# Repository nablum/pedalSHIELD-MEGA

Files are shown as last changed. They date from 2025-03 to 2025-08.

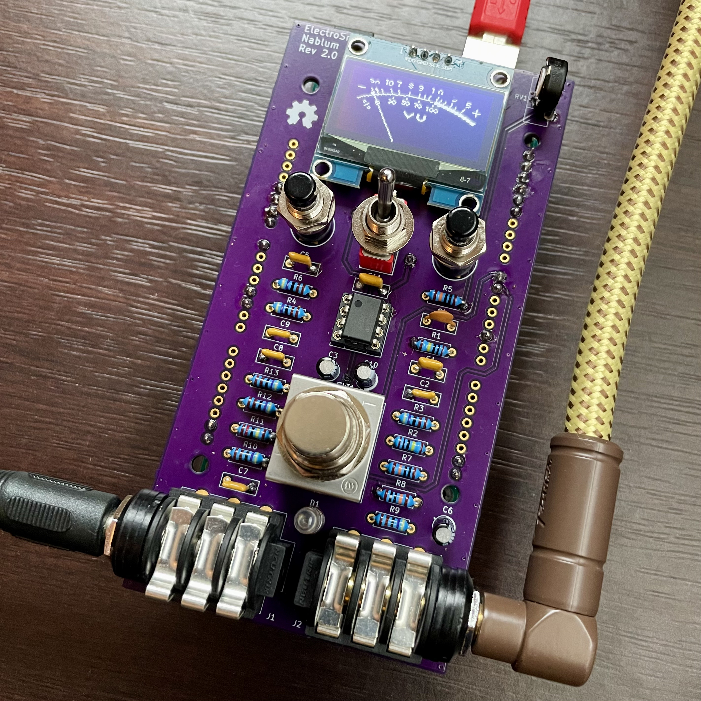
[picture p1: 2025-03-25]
hardware/kicad/pedalSHIELD_MEGA.jpg

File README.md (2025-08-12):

<p align="center">
    
</p>







A programmable guitar effects shield for Arduino MEGA, featuring OLED display, true-bypass footswitch, and DSP-ready input/output stages. Based on pedalSHIELD MEGA by [ElectroSmash](https://www.electrosmash.com/pedalshield-mega)  

<p align="center">
    device
</p>

## 📦 What’s Included

- ✅ **KiCad project**: schematic & PCB layout files for the hardware shield
- ✅ **Arduino examples**: boost, fuzz, delay, and other DSP sketches
- ✅ **Bill of Materials**: CSV file with component list and Mouser links
- ✅ **Documentation**: assembly guide, schematic diagrams, signal flow

## 🛠️ Assembly & Programming

1. **Clone the repository**:

    ```bash
    git clone https://github.com/nablum/pedalSHIELD-MEGA.git
    cd pedalSHIELD-MEGA
    ```

2. **Build the PCB** with KiCad or order the board from a fab using the provided Gerbers.

3. **Solder the components** according to the [Assembly Guide](https://www.electrosmash.com/media/kunena/attachments/631/How-to-Build-pedalSHIELD-MEGA-V1.1.pdf).

4. **Upload an effect sketch** to your Arduino MEGA using Arduino IDE.
5. **Plug and play**:
    - Guitar IN → Input Jack
    - Output → Amp or Audio Interface
    - Power → USB or DC JACK.

## 🎛️ Example Effects

Each audio effect is implemented in a separate folder under [`firmware/effects/`](./firmware/effects/):

| Effect Name | Description |
|---|---|
| BitCrusher | Reduces resolution and sample rate for lo-fi textures |
| Chorus | Modulates pitch with delay to create a thickening effect  |
| ChorusOrVibrato | Blendable chorus and vibrato with adjustable depth |
| Clean | Transparent clean boost (reference circuit) |
| Distortion | Hard-clipping distortion effect |
| Echo | Simple digital delay with feedback loop |
| Fuzz | Saturated high-gain fuzz effect |
| MultiEffects | Combination of multiple effects in a single patch |
| OctaveCrusher | Bit reduction with added octave-up/down harmonics |
| Octaver | Mixes original with octave-down processed signal |
| Reverb | Simulates ambient reverb using delay-based algorithm |
| Tremolo | Volume modulation using a low-frequency oscillator |
| Vibrato | Pitch modulation effect for expressive shimmer |

## ⚙️ Hardware Specs

- Compatible with **Arduino MEGA 2560**
- 128×64 I²C OLED display (SSD1306)
- True-bypass footswitch with relay
- Stereo audio jacks with analog preamp/output
- Powered via **12 V DC (center-negative)**

## ❓ Troubleshooting

- **OLED not lighting up** → Double-check I²C wiring and 4.7k pull-up resistors.
- **No audio output** → Ensure signal chain is complete and shield is powered.
- **Arduino upload fails** → Check USB port, board selection, and serial permissions.

## 📚 Resources

- 🔬 [pedalSHIELD-MEGA Documentation – ElectroSmash](https://www.electrosmash.com/pedalshield-mega)  
  Official guide, schematics, theory of operation, and signal path details.

- 🧰 [Assembly Guide – PDF](https://www.electrosmash.com/media/kunena/attachments/631/How-to-Build-pedalSHIELD-MEGA-V1.1.pdf)  
  Step-by-step instructions with images for building the pedalSHIELD‑MEGA hardware.

- 📦 [u8glib – OLED Display Library](https://github.com/olikraus/u8glib)  
  Arduino graphics library used to drive the OLED screen (SSD1306, I²C).

- 💻 [Arduino IDE Downloads](https://www.arduino.cc/en/software/)  
  Install the Arduino IDE to compile and upload code to the MEGA 2560.

## 🤝 Contributing

Contributions are welcome! You can:

- Submit new audio effects or improvements to existing sketches.
- Suggest hardware upgrades (e.g. better op-amps, analog filtering).
- Improve documentation or add new troubleshooting tips.

Please open a pull request against the `main` branch and follow the coding style of existing files.

## 📄 License

- **Hardware (PCB files, schematics, BOM)**:  
  Licensed under [Creative Commons Attribution-NonCommercial 3.0 (CC BY-NC 3.0)](https://creativecommons.org/licenses/by-nc/3.0/)

- **Software (Arduino code, examples)**:  
  Licensed under the [MIT License](LICENSE)

## 📬 Contact

Created by [@nablum](https://github.com/nablum).  
For questions or collaboration ideas, feel free to open an issue or reach out directly.

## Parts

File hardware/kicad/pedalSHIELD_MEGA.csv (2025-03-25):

Reference | Description | Mouser | Value | Qty
A1 | Shield for Arduino Mega 2560 R3 | 782-A000067 | ~ | 1
C1,C11 | Unpolarized capacitor | SR211C | 100n | 2
C2,C5,C7,C8,C9 | Unpolarized capacitor | SR211C | 6.8n | 5
C3,C6,C10 | Polarized capacitor | ECE-A1EKA4R7 | 4.7u | 3
C4 | Unpolarized capacitor | SR211C | 270p | 1
D1 | LED, 5mm | 696-SSL-LX3044USBC | ~ | 1
J1,J2 | Audio Jack, 3 Poles (Stereo / TRS), Switched Poles (Normalling) | NMJ6HCD2 | ~ | 2
LCD1 | I2C connector for LCD display |  | ~ | 1
R1,R2 | Resistor | MFR-25FRF52 | 1M | 2
R3,R4,R6,R9,R10,R12,R13,R14,R15 | Resistor | MFR-25FRF52 | 4.7k | 9
R5,R7,R8 | Resistor | MFR-25FRF52 | 100k | 3
R11 | Resistor | MFR-25FRF52 | 1M2 | 1
RV1 | Trim-potentiometer | PT10LH01-504A2020 | 500k | 1
SW1 | Pushbutton Switches 3PDT STOMP/FOOT SW LATCHING 1A9VDC 9PIN | 107-SF17020F-32-21RL | ~ | 1
SW2 | Switch, single pole double throw | 100SP1T1B1M1QEH | ~ | 1
SW3,SW4 | Push button switch, two pins | 104-0013-EVX | ~ | 2
U1 | TL97x Output Rail-To-Rail Very-Low-Noise Operational Amplifiers | 595-TL972IP | ~ | 1

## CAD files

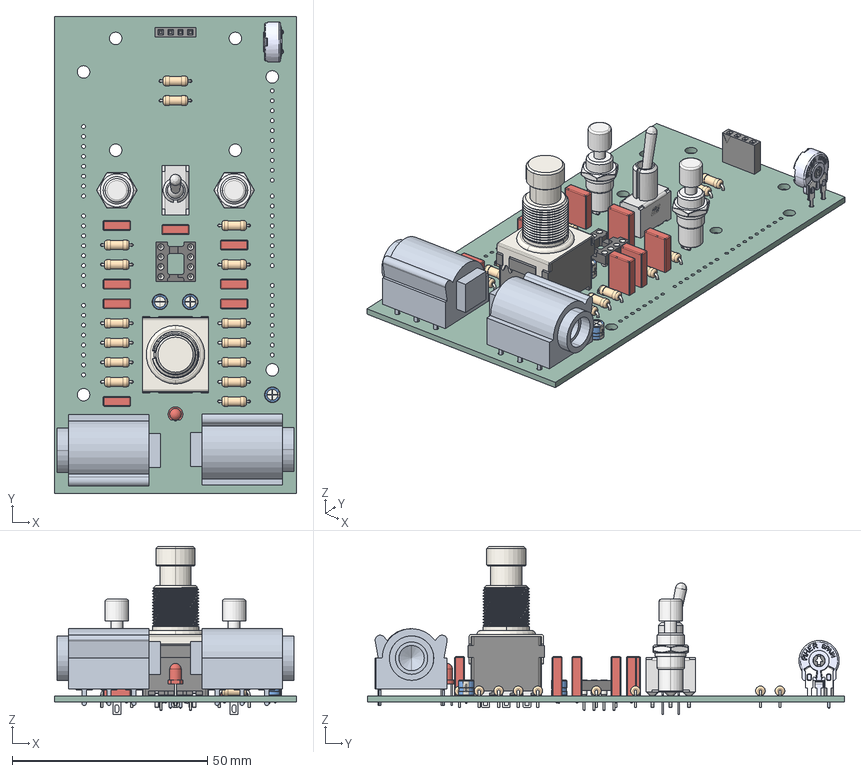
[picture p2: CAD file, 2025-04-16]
hardware/kicad/pedalSHIELD_MEGA.step
62.0 x 122.0 x 43.0 mm
C_Rect_L70mm_W25mm_P500mm x 8
ASSEMBLY
SF17020F-0302-21R-L-015
R_Axial_DIN0207_L63mm_D25mm_P762mm_Horizontal x 15
NMJ6HCD2 x 2
LED_D3.0mm
DIP_8_W762mm_Socket
CP_Radial_D40mm_P150mm x 3
P:\E-Switch Secure\3D_MODELS_STP_FORMAT\100SPxT1B1M1xE.stp
PT10_PTC10_10LH01
103-1013-EVX x 2
pedalSHIELD_MEGA_PCB

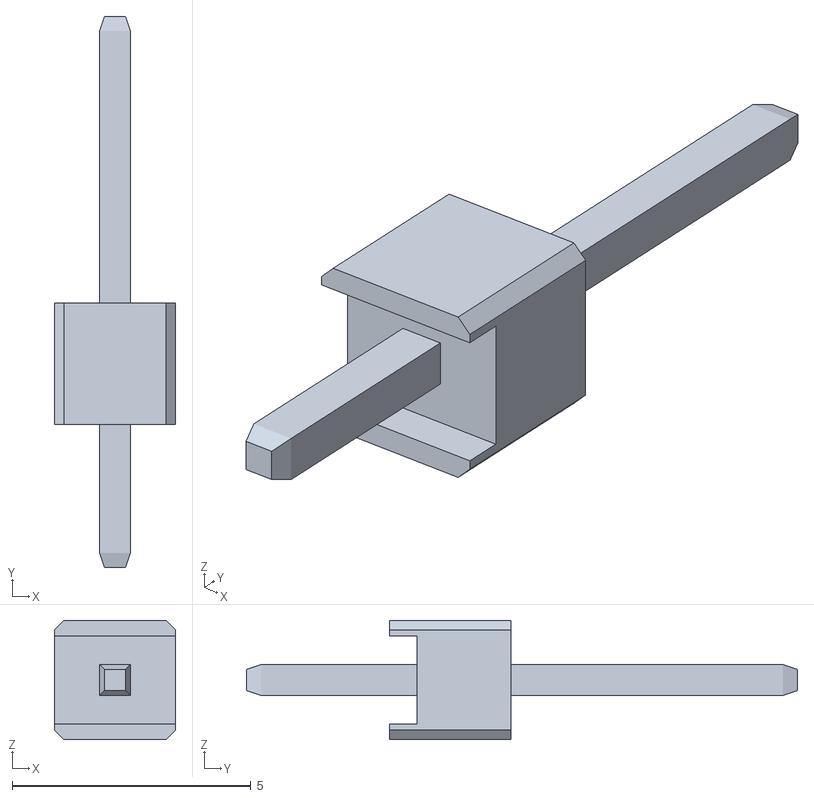
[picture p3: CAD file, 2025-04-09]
hardware/openscad/model3D/pinHeader.stl
2.54 x 11.5 x 2.50

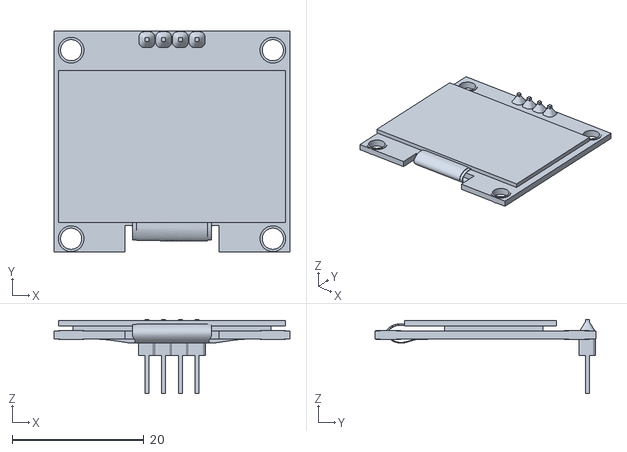
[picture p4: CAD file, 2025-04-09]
hardware/openscad/model3D/displayOLED.stl
35.8 x 33.5 x 11.3

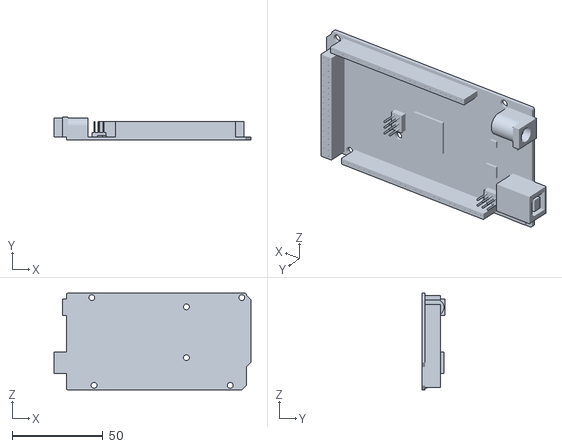
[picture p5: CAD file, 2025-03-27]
hardware/openscad/model3D/ArduinoMega_2560.stl
108.3 x 12.5 x 53.3

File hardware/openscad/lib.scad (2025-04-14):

// Licensed under a Creative Commons Attribution 4.0 International License.

// Library
include <NopSCADlib/lib.scad>

// Modules
module importPedal(){
    // Origin alignment
    translate([0.5,11.5,0]){
        // Arduino Mega
        rotate([90,0,-90]) import("./model3D/ArduinoMega_2560.stl");
        // PCB
        translate([-0.5,-11.5,12]) import("./model3D/pedalSHIELD_MEGA.stl");
        // LCD
        translate([-0.5,29.6,24.8]) import("./model3D/displayOLED.stl");
        // Pin headers
        generate_pin_header(8,[24.3,-37.1,12],"z","y","up"); // Bottom right side
        generate_pin_header(8,[24.3,-14.3,12],"z","y","up"); // Middle right side
        generate_pin_header(10,[24.3,7.6,12],"z","y","up"); // Top right side
        generate_pin_header(8,[-24,-42.2,12],"z","y","up"); // Bottom left side
        generate_pin_header(8,[-24,-19.3,12],"z","y","up"); // Middle left side
        generate_pin_header(8,[-24,3.5,12],"z","y","up"); // Top left side
    }
}

module buildTopPanel(){
    difference(){
        // Top panel
        translate([0,0,$sideHeight-$topThickness/2]){
            cube([$caseWidth+2*$sideThickness*$topSideOverlap,$caseLength+2*$sideThickness*$topSideOverlap,$topThickness],center=true);
        }
        // Footswitch hole
        translate(concat($footSwitchHolePosition,$sideHeight-$topThickness/2)){ 
            cylinder($topThickness+$fs,d1=$footSwitchHoleDiameter,d2=$footSwitchHoleDiameter,center=true);
        }
        // Push button left
        translate(concat($pushButtonHolePosition[0],$sideHeight-$topThickness/2)){ 
            cylinder($topThickness+$fs,d1=$pushButtonHoleDiameter,d2=$pushButtonHoleDiameter,center=true);
        } 
        // Push button right
        translate(concat($pushButtonHolePosition[1],$sideHeight-$topThickness/2)){ 
            cylinder($topThickness+$fs,d1=$pushButtonHoleDiameter,d2=$pushButtonHoleDiameter,center=true);
        }
        // Toggle switch
        translate(concat($toggleSwitchHolePosition,$sideHeight-$topThickness/2)){ 
            cylinder($topThickness+$fs,d1=$toggleSwitchHoleDiameter,d2=$toggleSwitchHoleDiameter,center=true);
        }
        // LCD window
        if ($lcdWindowEnable){
            translate(concat($lcdWindowPosition,$sideHeight-$topThickness/2)){
                cube([$lcdWindowWidth,$lcdWindowLength,$topThickness+$fs],center=true);
            }
        }
        // Mount holes
        addMounts();
    }
}

module buildBottomPanel(){
    difference(){
        translate([0,0,-$baseThickness/2]) cube([$caseWidth,$caseLength,$baseThickness],center=true); // Base
        translate([0.5,11.5,-$cavityHeight/2]) cube([$cavityWidth,$cavityLength,$cavityHeight+$fs],center=true); // Cavity
        for(i=[0:len($screwPosition)-1]){ // Mount holders
            translate([$screwPosition[i][0],$screwPosition[i][1],-((nut_thickness($nutType)+$cavityHeight)/2)]){
                cylinder(nut_thickness($nutType)+$cavityHeight+$fs,nut_radius($nutType)+$fs,nut_radius($nutType)+$fs,$fn=6,center=true);
            }
        }
    }
}

module buildLeftPanel(){
    difference(){
        // Panel
        translate([-($caseWidth+$sideThickness)/2,0,($sideHeight-$baseThickness)/2]){
            cube([$sideThickness,$caseLength+2*$sideThickness,$sideHeight+$baseThickness],center=true);
        }
        // Jack connector hole
        translate(concat(-($caseWidth+$sideThickness)/2,$audioJackHolePosition[0][0],$audioJackHolePosition[0][1])){ 
            rotate([0,90,0]){ 
                cylinder($sideThickness+$fs,d1=$audioJackHoleDiameter,d2=$audioJackHoleDiameter,center=true);
            }
        }
        // Top panel overlap
        translate([0,0,$sideHeight-$topThickness/2]){
            cube([$caseWidth+2*$sideThickness*$topSideOverlap,$caseLength+2*$sideThickness*$topSideOverlap,$topThickness+$fs],center=true);
        }
    }
}

module buildRightPanel(){
    difference(){
        // Panel
        translate([($caseWidth+$sideThickness)/2,0,($sideHeight-$baseThickness)/2]){
            cube([$sideThickness,$caseLength+2*$sideThickness,$sideHeight+$baseThickness],center=true);
        }
        // Jack connector hole
        translate(concat(($caseWidth+$sideThickness)/2,$audioJackHolePosition[1][0],$audioJackHolePosition[1][1])){ 
            rotate([0,90,0]){ 
                cylinder($sideThickness+$fs,d1=$audioJackHoleDiameter,d2=$audioJackHoleDiameter,center=true);
            }
        }
        // Potentiometer hole
        translate(concat(($caseWidth+$sideThickness)/2,$potHolePosition[0],$potHolePosition[1])){ 
            rotate([0,90,0]){ 
                cylinder($sideThickness+$fs,d1=$potHoleDiameter,d2=$potHoleDiameter,center=true);
            }
        }
        // Top panel overlap
        translate([0,0,$sideHeight-$topThickness/2]){
            cube([$caseWidth+2*$sideThickness*$topSideOverlap,$caseLength+2*$sideThickness*$topSideOverlap,$topThickness+$fs],center=true);
        }
    }
}

module buildBackPanel(){
    difference(){
        // Panel
        translate([0,-($caseLength+$sideThickness)/2,($sideHeight-$baseThickness)/2]){
            cube([$caseWidth+2*$sideThickness,$sideThickness,$sideHeight+$baseThickness],center=true);
        }
        // Top panel overlap
        translate([0,0,$sideHeight-$topThickness/2]){
            cube([$caseWidth+2*$sideThickness*$topSideOverlap,$caseLength+2*$sideThickness*$topSideOverlap,$topThickness+$fs],center=true);
        }
    }
}

module buildFrontPanel(){
    difference(){
        // Panel
        translate([0,($caseLength+$sideThickness)/2,($sideHeight-$baseThickness)/2]){
            cube([$caseWidth+2*$sideThickness,$sideThickness,$sideHeight+$baseThickness],center=true);
        }
        // USB Hole
        translate([$usbHolePosition[0],($caseLength+$sideThickness)/2,$usbHolePosition[1]]){
            cube([$usbHoleWidth,$sideThickness+$fs,$usbHoleHeight],center=true);
        }
        // Power supply connector
        translate([$dcJackHolePosition[0],($caseLength+$sideThickness)/2,$dcJackHolePosition[1]]){
            cube([$dcJackHoleWidth,$sideThickness+$fs,$dcJackHoleHeight],center=true);
        }
        // Top panel overlap
        translate([0,0,$sideHeight-$topThickness/2]){
            cube([$caseWidth+2*$sideThickness*$topSideOverlap,$caseLength+2*$sideThickness*$topSideOverlap,$topThickness+$fs],center=true);
        }
    }
}

module import_pin_header(rotation=[0,0,0],translation=[0,0,0]){
    rotate(rotation){ 
        translate(translation){
            import("./model3D/pinHeader.stl");
        }
    }
}
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

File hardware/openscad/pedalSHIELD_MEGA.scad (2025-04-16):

// Licensed under a Creative Commons Attribution 4.0 International License.

// *** LIBRARY *** //
include <lib.scad>

// *** VISUALISATION *** //
view = "assembly"; // choose between "assembly", "printing", "cutting"
printing = true; // True for 3D print

// *** DIMENSIONS *** //
// System
$fa = 1; // Minimum angle
$fs = 0.1; // Minimum size

// Pedal
pedalWidth = 62;
pedalLength = 122;
pedalHeight = 33;

// Arduino
arduinoWidth = 53;
arduinoLength = 99;
arduinoHeight = 15;
arduinoWeldsHeight = 2.5;

// Cavity (to avoid conflict with arduino's welds)
$cavityWidth = arduinoWidth-2;
$cavityLength = arduinoLength-2;
$cavityHeight = arduinoWeldsHeight+0.5;

// Mounts
$nutType = M3_nut;
$screwType = M3_dome_screw;
$screwPosition = [[24.68,45.65], // X/Y
                  [24.68,-29.25],
                  [-23.55,46.9],
                  [-23.55,-35.6]];

// Case
$caseWidth = pedalWidth+0.5;
$caseLength = pedalLength+0.5;
$baseThickness = $cavityHeight+nut_thickness($nutType)+2;
$sideHeight = 34;
$sideThickness = 2;
$topThickness = 2;
$topSideOverlap = 0.5;

// Audio jack
$audioJackHoleDiameter = 12;
$audioJackHolePosition = [[-49.8,23.2], // Y/Z - Left/Right
                          [-49.8,23.2]]; 

// DC jack
$dcJackHolePosition = [-18.3,7.1]; // X/Z
$dcJackHoleWidth = 9.5;
$dcJackHoleHeight = 12;

// USB
$usbHolePosition = [12.1,7]; // X/Z
$usbHoleWidth = 13;
$usbHoleHeight = 12.5;

// Potentiometer
$potHoleDiameter = 4;
$potHolePosition = [54.5,22.6]; // Y/Z

// Foot switch
$footSwitchHoleDiameter = 12.6;
$footSwitchHolePosition = [0,-25.5]; // X/Y

// Push buttons
$pushButtonHoleDiameter = 7;
$pushButtonHolePosition = [[-15,16.5], // X/Y - Left/Right
                           [15,16.5]];

// Toggle switch
$toggleSwitchHoleDiameter = 7;
$toggleSwitchHolePosition = [0,16.5]; // X/Y

// LCD window
$lcdWindowEnable = false;
$lcdWindowWidth = 31;
$lcdWindowLength = 16;
$lcdWindowPosition = [0,44];

// *** DESIGN *** //
if(view=="assembly") buildCase();
if(view=="printing") printCase();
if(view=="cutting") cutCase();

// *** MODULES *** //
module buildCase(){
    importPedal();
    addMounts();
    buildBottomPanel();
    buildLeftPanel();
    buildRightPanel();
    buildBackPanel(); 
    buildFrontPanel();
    color(alpha=0.5) buildTopPanel();
}

module printCase(){
    translate([0,0,$baseThickness]){
        buildBottomPanel();
        buildLeftPanel();
        buildRightPanel();
        buildBackPanel(); 
        buildFrontPanel();
    }
    translate([$caseWidth+5,0,-$sideHeight+$topThickness]){
        buildTopPanel();
    }
}

module cutCase(){
    projection(cut = false){
        buildTopPanel();
    }    
}

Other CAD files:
hardware/openscad/model3D/pedalSHIELD_MEGA.stl
hardware/openscad/pedalSHIELD_MEGA.stl

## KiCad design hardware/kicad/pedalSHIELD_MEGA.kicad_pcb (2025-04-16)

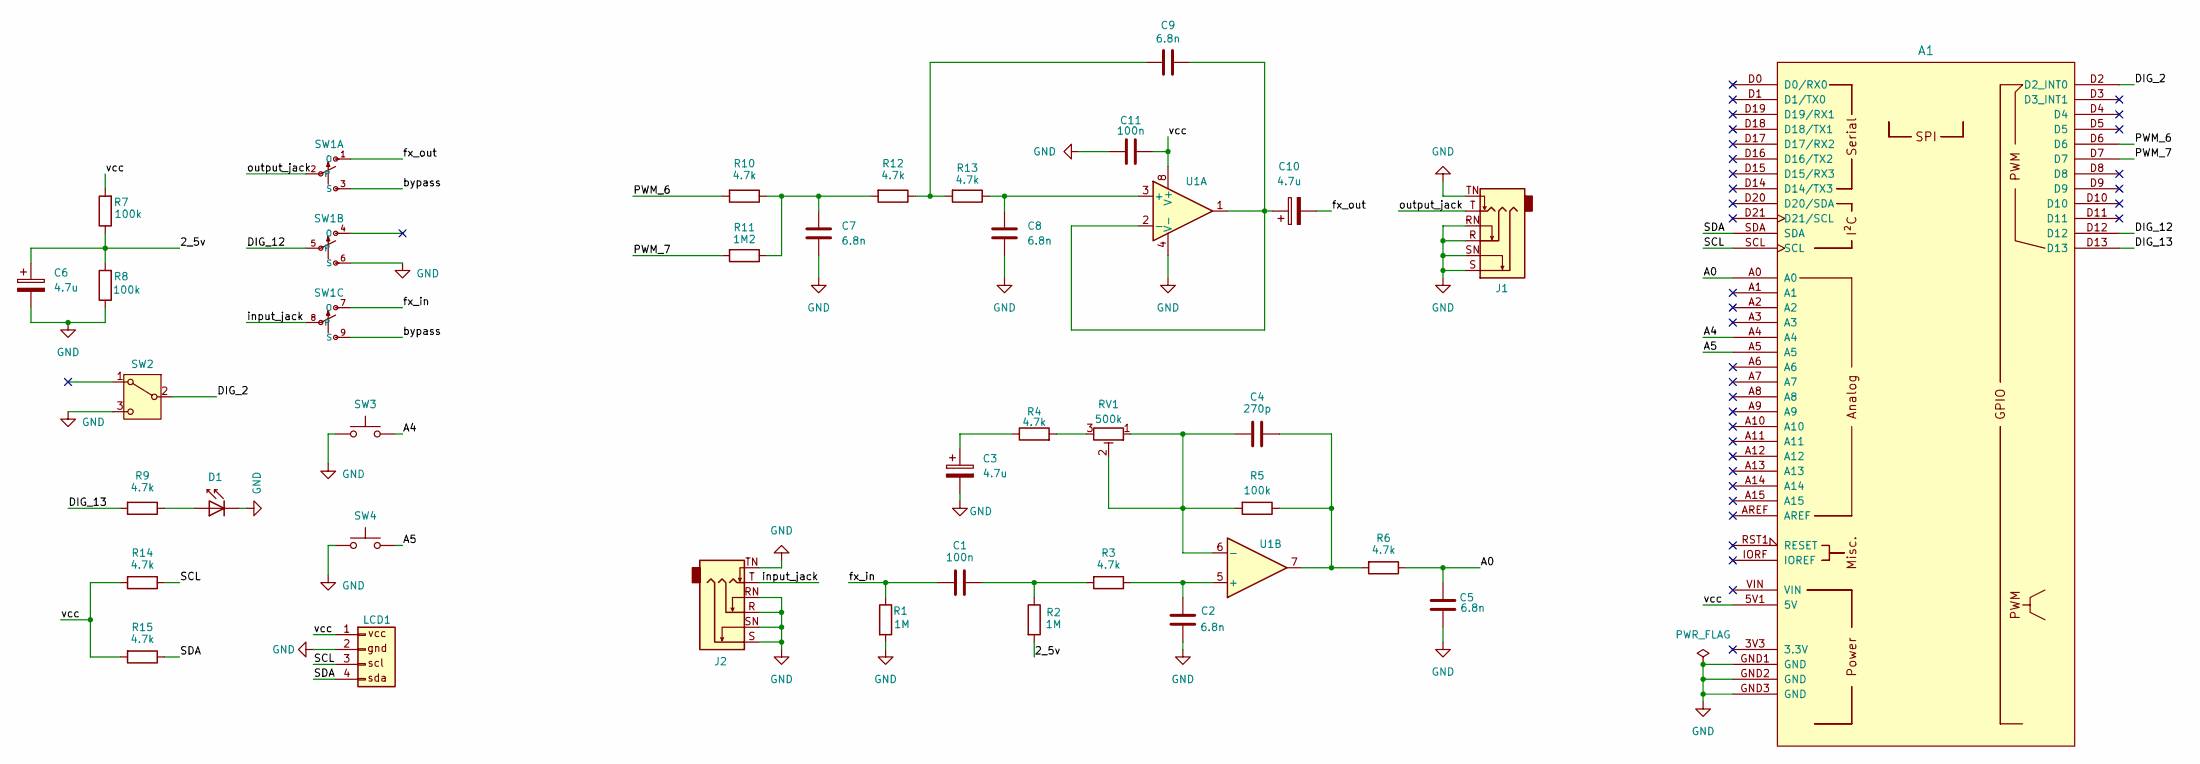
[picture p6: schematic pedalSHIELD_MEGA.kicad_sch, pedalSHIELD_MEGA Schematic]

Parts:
A1: Arduino_Mega2560_R3_Shield_pedalSHIELD_MEGA; Mouser 782-A000067
C1, C11: 100n; C_Rect_L7.0mm_W2.5mm_P5.00mm; Mouser SR211C
C2, C5, C7, C8, C9: 6.8n; C_Rect_L7.0mm_W2.5mm_P5.00mm; Mouser SR211C
C3, C6, C10: 4.7u; CP_Radial_D4.0mm_P1.50mm; Mouser ECE-A1EKA4R7
C4: 270p; C_Rect_L7.0mm_W2.5mm_P5.00mm; Mouser SR211C
D1: LED_D3.0mm; Mouser 696-SSL-LX3044USBC
J1, J2: Jack_6.35mm_Neutrik_NMJ6HCD2_Horizontal; Mouser NMJ6HCD2
LCD1: LCD_OLED_SH1106
R1, R2: 1M; R_Axial_DIN0207_L6.3mm_D2.5mm_P7.62mm_Horizontal; Mouser MFR-25FRF52
R3, R4, R6, R9, R10, R12, R13, R14, R15: 4.7k; R_Axial_DIN0207_L6.3mm_D2.5mm_P7.62mm_Horizontal; Mouser MFR-25FRF52
R5, R7, R8: 100k; R_Axial_DIN0207_L6.3mm_D2.5mm_P7.62mm_Horizontal; Mouser MFR-25FRF52
R11: 1M2; R_Axial_DIN0207_L6.3mm_D2.5mm_P7.62mm_Horizontal; Mouser MFR-25FRF52
RV1: 500k; Potentiometer_Piher_PT-10-H01_Horizontal; Mouser PT10LH01-504A2020
SW1: SF17020F030221RL015; Manufacturer_Part_Number SF17020F-0302-21R-L-015; Mouser 107-SF17020F-32-21RL
SW2: SW_SPDT_ 100SP1T1B1M1QEH; Mouser 100SP1T1B1M1QEH
SW3, SW4: SW_PUSH_104-0013-EVX; Mouser 104-0013-EVX
U1: DIP-8_W7.62mm_Socket_LongPads; Mouser 595-TL972IP

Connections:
/2_5v: C6.1, R2.2, R7.1, R8.2
/A0: A1.A0, C5.1, R6.1
/A4: A1.A4, SW3.2
/A5: A1.A5, SW4.2
/DIG_2: A1.D2 (D2_INT0), SW2.2 (B)
/DIG_12: A1.D12, SW1.5
/DIG_13: A1.D13, R9.2
/PWM_6: A1.D6, R10.2
/PWM_7: A1.D7, R11.2
/SCL: A1.SCL, LCD1.3, R14.1
/SDA: A1.SDA, LCD1.4, R15.1
/bypass: SW1.3 (S), SW1.9 (S)
/fx_in: C1.1, R1.1, SW1.7 (O)
/fx_out: C10.2, SW1.1 (O)
/input_jack: J2.T, SW1.8
/output_jack: J1.T, SW1.2
/vcc: A1.5V1 (5V), C11.2, LCD1.1, R7.2, R14.2, R15.2, U1.8 (V+)
GND: A1.GND1 (GND), A1.GND2 (GND), A1.GND3 (GND), C2.2, C3.2, C5.2, C6.2, C7.2, C8.2, C11.1, D1.1 (K), J1.R, J1.RN, J1.S, J1.SN, J1.TN, J2.R, J2.RN, J2.S, J2.SN, J2.TN, LCD1.2, R1.2, R8.1, SW1.6 (S), SW2.3 (C), SW3.1, SW4.1, U1.4 (V-)
unnamed: C1.2, R2.1, R3.2
unnamed: C3.1, R4.1
unnamed: C4.2, R5.1, R6.2, U1.7
unnamed: C7.1, R10.1, R11.1, R12.2
unnamed: C9.1, R12.1, R13.2
unnamed: D1.2 (A), R9.1
unnamed: R4.2, RV1.3
unnamed: C8.1, R13.1, U1.3 (+)
unnamed: C9.2, C10.1, U1.1, U1.2 (-)
unnamed: C2.1, R3.1, U1.5 (+)
unnamed: C4.1, R5.2, RV1.1, RV1.2, U1.6 (-)

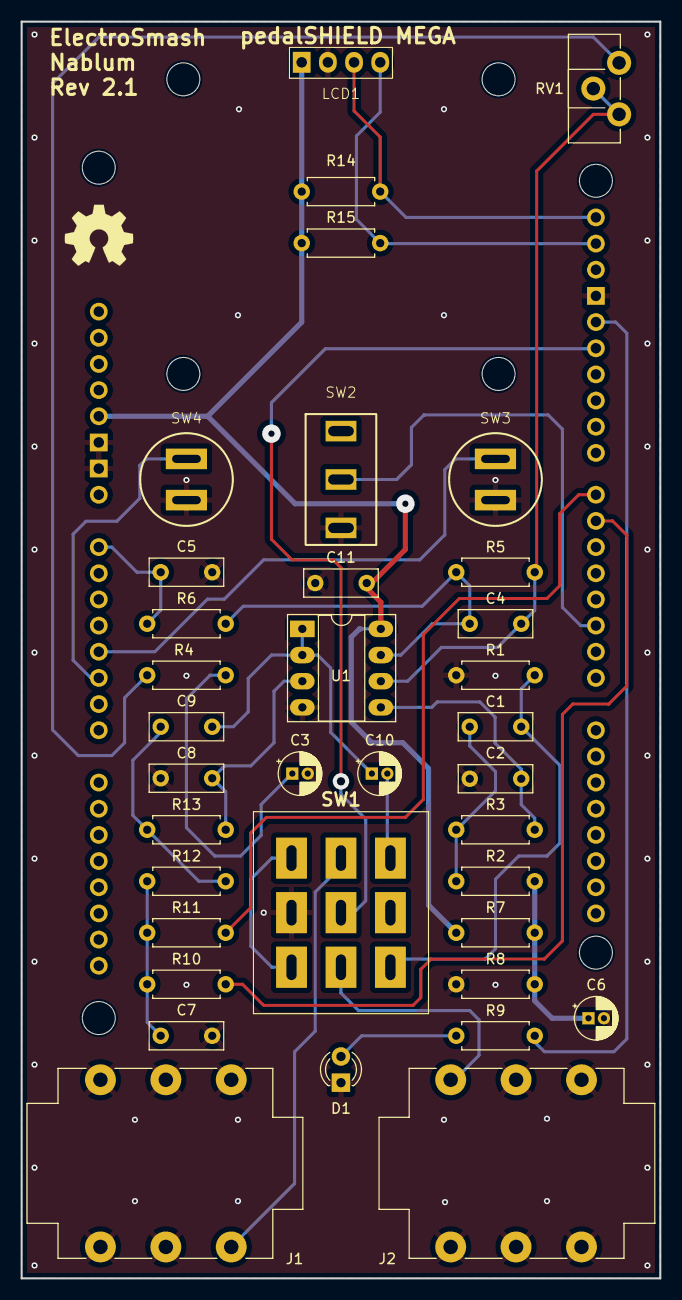
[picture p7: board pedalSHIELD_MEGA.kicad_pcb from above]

Board: 2 copper layers, 62.0 x 122.0 mm, 37 parts (0 on the bottom side), 29 nets.

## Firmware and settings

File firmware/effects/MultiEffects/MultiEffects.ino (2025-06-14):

/*
  MultiEffects.ino allows selection between delay, echo, distortion, fuzz, 
  bit-crusher, octaver, octave crusher, vibrato and chorus effects.

  Part of the pedalSHIELD-MEGA project: https://github.com/nablum/pedalSHIELD-MEGA

  Copyright (c) 2025 Nablum
  SPDX-License-Identifier: MIT

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
  THE SOFTWARE IS PROVIDED "AS IS", WITHOUT WARRANTY OF ANY KIND, EXPRESS OR
  IMPLIED, INCLUDING BUT NOT LIMITED TO THE WARRANTIES OF MERCHANTABILITY,
  FITNESS FOR A PARTICULAR PURPOSE AND NONINFRINGEMENT. IN NO EVENT SHALL THE
  AUTHORS OR COPYRIGHT HOLDERS BE LIABLE FOR ANY CLAIM, DAMAGES OR OTHER
  LIABILITY, WHETHER IN AN ACTION OF CONTRACT, TORT OR OTHERWISE, ARISING FROM,
  OUT OF OR IN CONNECTION WITH THE SOFTWARE OR THE USE OR OTHER DEALINGS IN THE
  SOFTWARE.
*/

//display parameters
#include "U8glib.h"
U8GLIB_SH1106_128X64 u8g(U8G_I2C_OPT_NO_ACK);
 
//defining hardware resources
#define LED 13
#define FOOTSWITCH 12
#define TOGGLE 2
#define PUSHBUTTON_1 A5
#define PUSHBUTTON_2 A4

//defining the output PWM parameters
#define PWM_FREQ 0x00FF // pwm frequency - 31.3KHz
#define PWM_MODE 0 // Fast (1) or Phase Correct (0)
#define PWM_QTY 2 // 2 PWMs in parallel

//system variables
int output;
int counter = 0;
int effect = 1;
unsigned int ADC_low, ADC_high;

//effect variables
#define EFFECT_NUMBER 9
#define MAX_DELAY 5000
#define MIN_DELAY 20
#define MAX_BIT 8
#define MIN_BIT 1
#define MAX_LEVEL 32768
#define MIN_LEVEL 1000
#define MAX_octaveCrusher 50
#define MIN_octaveCrusher 1
#define MAX_VIBRATO 200
#define MIN_VIBRATO 10
#define MAX_CHORUS 200
#define MIN_CHORUS 10
byte audioBuffer[MAX_DELAY];
int audioCounter = 0;
int delayDepth = 1000;
int echoDepth = 4000;
int octaverDelay = 1000;
int vibratoDepth = 100;
int chorusDepth = 100;
int lfoDepth = 100;
int distortion = 6000;
int fuzz = 6000;
int bitCrush = 2;
int octaveCrusher = 15;
bool octaverMode = 0;
bool countUp = false;
bool writePWM = true;
 
void setup() 
{ 
  //setup IO
  pinMode(FOOTSWITCH, INPUT_PULLUP);
  pinMode(TOGGLE, INPUT_PULLUP);
  pinMode(PUSHBUTTON_1, INPUT_PULLUP);
  pinMode(PUSHBUTTON_2, INPUT_PULLUP);
  pinMode(LED, OUTPUT);
  pinMode(6, OUTPUT); //PWM0 as output
  pinMode(7, OUTPUT); //PWM1 as output
 
  //setup ADC
  ADMUX = 0x60; // left adjust, adc0, internal vcc
  ADCSRA = 0xe5; // turn on adc, ck/32, auto trigger
  ADCSRB = 0x00; // ADC free running mode
  DIDR0 = 0x01; // turn off digital inputs for adc0
 
  //setup PWM
  TCCR4A = (((PWM_QTY - 1) << 5) | 0x80 | (PWM_MODE << 1)); //
  TCCR4B = ((PWM_MODE << 3) | 0x11); // ck/1
  TIMSK4 = 0x20; // interrupt on capture interrupt
  ICR4H = (PWM_FREQ >> 8);
  ICR4L = (PWM_FREQ & 0xff);
  DDRB |= ((PWM_QTY << 1) | 0x02); // turn on outputs
  sei(); // turn on interrupts - not really necessary with arduino  
}
 
void loop() 
{
  /* selection mode */
  // program stays in this loop while the toggle switch is down, you can change effect by pushing buttons.
  while(digitalRead(TOGGLE) && digitalRead(FOOTSWITCH))
  { 
    digitalWrite(LED, HIGH);
    if(!digitalRead(PUSHBUTTON_2)) if(effect<EFFECT_NUMBER) effect++;
    if(!digitalRead(PUSHBUTTON_1)) if(effect>1) effect--;
    switch(effect)
    {
      case 1: //1st effect
      u8g.firstPage();
      do {
          u8g.setFont(u8g_font_helvR14r);
          u8g.drawStr( 10, 16, "SELECTION");    
          u8g.drawStr( 32, 50, "DELAY");
          } while( u8g.nextPage() );
      break;
      case 2: //2nd effect
      u8g.firstPage();
      do {
          u8g.setFont(u8g_font_helvR14r);
          u8g.drawStr( 10, 16, "SELECTION");    
          u8g.drawStr( 35, 50, "ECHO");
          } while( u8g.nextPage() );
      break;
      case 3: //3rd effect
      u8g.firstPage();
      do {
          u8g.setFont(u8g_font_helvR14r);
          u8g.drawStr( 10, 16, "SELECTION");    
          u8g.drawStr( 5, 50, "DISTORTION");
          } while( u8g.nextPage() );
      break;
      case 4: //4th effect
      u8g.firstPage();
      do {
          u8g.setFont(u8g_font_helvR14r);
          u8g.drawStr( 10, 16, "SELECTION");    
          u8g.drawStr( 38, 50, "FUZZ");
          } while( u8g.nextPage() );
      break;
      case 5: //5th effect
      u8g.firstPage();
      do {
          u8g.setFont(u8g_font_helvR14r);
          u8g.drawStr( 10, 16, "SELECTION");    
          u8g.drawStr( 0, 50, "BIT CRUSHER");
          } while( u8g.nextPage() );
      break;
      case 6: //6th effect
      u8g.firstPage();
      do {
          u8g.setFont(u8g_font_helvR14r);
          u8g.drawStr( 10, 16, "SELECTION");    
          u8g.drawStr( 18, 50, "OCTAVER");
          } while( u8g.nextPage() );
      break;
      case 7: //7th effect
      u8g.firstPage();
      do {
          u8g.setFont(u8g_font_helvR14r);
          u8g.drawStr( 10, 16, "SELECTION");    
          u8g.setFont(u8g_font_helvR10r);
          u8g.drawStr( 0, 50, "OCTAVE CRUSHER");
          } while( u8g.nextPage() );
      break;
      case 8: //8th effect
      u8g.firstPage();
      do {
          u8g.setFont(u8g_font_helvR14r);
          u8g.drawStr( 10, 16, "SELECTION");    
          u8g.drawStr( 22, 50, "VIBRATO");
          } while( u8g.nextPage() );
      break;
      case 9: //9th effect
      u8g.firstPage();
      do {
          u8g.setFont(u8g_font_helvR14r);
          u8g.drawStr( 10, 16, "SELECTION");    
          u8g.drawStr( 22, 50, "CHORUS");
          } while( u8g.nextPage() );
      break;
    }
  }
  /* effect mode */
  if (digitalRead(FOOTSWITCH)) 
  {
    digitalWrite(LED, HIGH);
    switch(effect)
    {
      case 1: //1st effect
      u8g.firstPage();
      do {
          u8g.setFont(u8g_font_helvR14r);
          u8g.drawStr( 0, 16, "DELAY");    
          u8g.setPrintPos(10, 50); 
          u8g.setFont(u8g_font_helvR24r); 
          u8g.print(delayDepth);
          } while( u8g.nextPage() );
      break;
      case 2: //2nd effect
      u8g.firstPage();
      do {
          u8g.setFont(u8g_font_helvR14r);
          u8g.drawStr( 0, 16, "ECHO");    
          u8g.setPrintPos(10, 50); 
          u8g.setFont(u8g_font_helvR24r); 
          u8g.print(echoDepth);
          } while( u8g.nextPage() );
      break;
      case 3: //3rd effect
      u8g.firstPage();
      do {
          u8g.setFont(u8g_font_helvR14r);
          u8g.drawStr( 0, 16, "DISTORTION");    
          u8g.setPrintPos(10, 50); 
          u8g.setFont(u8g_font_helvR24r); 
          u8g.print(distortion);
          } while( u8g.nextPage() );
      break;
      case 4: //4th effect
      u8g.firstPage();
      do {
          u8g.setFont(u8g_font_helvR14r);
          u8g.drawStr( 0, 16, "FUZZ");    
          u8g.setPrintPos(10, 50); 
          u8g.setFont(u8g_font_helvR24r); 
          u8g.print(fuzz);
          } while( u8g.nextPage() );
      break;
      case 5: //5th effect
      u8g.firstPage();
      do {
          u8g.setFont(u8g_font_helvR14r);
          u8g.drawStr( 0, 16, "BIT CRUSHER");    
          u8g.setPrintPos(10, 50); 
          u8g.setFont(u8g_font_helvR24r); 
          u8g.print(bitCrush);
          } while( u8g.nextPage() );
      break;
      case 6: //6th effect
      u8g.firstPage();
      do {
          u8g.setFont(u8g_font_helvR14r);
          u8g.drawStr( 18, 16, "OCTAVER");
          switch(octaverMode){
            case true: u8g.drawStr( 52, 50, "UP"); break;
            case false: u8g.drawStr( 35, 50, "DOWN"); break;
          } 
      } while( u8g.nextPage() );
      break;
      case 7: //7th effect
      u8g.firstPage();
      do {
        u8g.setFont(u8g_font_helvR10r);
        u8g.drawStr( 0, 16, "OCTAVE CRUSHER");
        u8g.setPrintPos(45, 50); 
        u8g.setFont(u8g_font_helvR24r); 
        u8g.print(octaveCrusher);
      } while( u8g.nextPage() );
      break;
      case 8: //8th effect
      u8g.firstPage();
      do {
        u8g.setFont(u8g_font_helvR14r);
        u8g.drawStr( 22, 16, "VIBRATO");
        u8g.setFont(u8g_font_helvR24r); 
        u8g.setPrintPos(10, 60); 
        u8g.print(vibratoDepth);
        u8g.setFont(u8g_font_helvR14r); 
        u8g.setPrintPos(100, 60); 
        u8g.print(countUp);

      } while( u8g.nextPage() );
      break;
      case 9: //9th effect
      u8g.firstPage();
      do {
        u8g.setFont(u8g_font_helvR14r);
        u8g.drawStr( 22, 16, "CHORUS");
        u8g.setFont(u8g_font_helvR24r); 
        u8g.setPrintPos(10, 60); 
        u8g.print(chorusDepth);
        u8g.setFont(u8g_font_helvR14r); 
        u8g.setPrintPos(100, 60); 
        u8g.print(countUp);

      } while( u8g.nextPage() );
      break;
    } 
  }
  else  
  {  
   digitalWrite(LED, LOW);
    u8g.firstPage(); 
    do {
      u8g.setFont(u8g_font_helvR24r);
      u8g.drawStr( 0, 30, "EFFECT");    
      u8g.drawStr( 32, 60, "OFF");   
    } while( u8g.nextPage() );
  }
}
 
ISR(TIMER4_CAPT_vect) 
{
  //button status
  counter++; 
  if(counter==2000)
  {
    counter=0;
    //increase
    if (!digitalRead(PUSHBUTTON_2) && !digitalRead(TOGGLE)) 
    {
      switch(effect)
      {
        case 1: //1st effect
        if (delayDepth<MAX_DELAY)delayDepth+=25; //increase delay
        break;
        case 2: //2nd effect
        if (echoDepth<MAX_DELAY)echoDepth+=25; //increase echo
        break;
        case 3: //3rd effect
        if (distortion<MAX_LEVEL)distortion+=25; //increase distortion threshold
        break;
        case 4: //4th effect
        if (fuzz<MAX_LEVEL)fuzz+=25; //increase fuzz threshold
        break;
        case 5: //5th effect
        if (bitCrush<MAX_BIT)bitCrush++; //increase the number of crushed bits
        break;
        case 6: //6th effect
        if(!octaverMode)octaverMode=true; //change the octave mode
        break;
        case 7: //7th effect
        if (octaveCrusher<MAX_octaveCrusher)octaveCrusher++; //increase octave crusher
        break;
        case 8: //8th effect
        if (vibratoDepth<MAX_VIBRATO)vibratoDepth++; //increase vibrato depth
        break;
        case 9: //9th effect
        if (chorusDepth<MAX_CHORUS)chorusDepth++; //increase chorus depth
        break;
      }
    }
    //decrease
    if (!digitalRead(PUSHBUTTON_1) && !digitalRead(TOGGLE)) 
    {
      switch(effect)
      {
        case 1: //1st effect
        if (delayDepth>MIN_DELAY)delayDepth-=25; //decrease delay
        break;
        case 2: //2nd effect
        if (echoDepth>MIN_DELAY)echoDepth-=25; //decrease echo
        break;
        case 3: //3rd effect
        if (distortion>MIN_LEVEL)distortion-=25; //decrease distortion threshold
        break;
        case 4: //4th effect
        if (fuzz>MIN_LEVEL)fuzz-=25; //decrease fuzz threshold
        break;
        case 5: //5th effect
        if (bitCrush>MIN_BIT)bitCrush--; //decrease the number of crushed bits
        break;
        case 6: //6th effect
        if (octaverMode)octaverMode=false; //change the octave mode
        break;
        case 7: //7th effect
        if (octaveCrusher>MIN_octaveCrusher)octaveCrusher--; //decrease octave crusher
        break;
        case 8: //8th effect
        if (vibratoDepth>MIN_VIBRATO)vibratoDepth--; //decrease vibrato depth
        break;
        case 9: //9th effect
        if (chorusDepth>MIN_CHORUS)chorusDepth--; //decrease chorus depth
        break;
      }
    }
  }

  //get ADC data
  ADC_low = ADCL;
  ADC_high = ADCH;
  
  //construct the input sample summing the ADC low and high byte.
  output = ((ADC_high << 8) | ADC_low) + 0x8000;

  //audio processing
  switch(effect)
  {
    case 1: //1st effect: delay
    audioBuffer[audioCounter] = ADC_high>>1 ; 
    audioCounter++;
    if(audioCounter >= delayDepth) audioCounter = 0; 
    output = ((((audioBuffer[audioCounter]+(ADC_high))>>1) << 8) | ADC_low) + 0x8000;
    break;

    case 2: //2nd effect: echo
    audioBuffer[audioCounter] = (ADC_high + audioBuffer[audioCounter])>>1 ; 
    audioCounter++;
    if(audioCounter >= echoDepth) audioCounter = 0; 
    output = ((((audioBuffer[audioCounter]+(ADC_high))>>1) << 8) | ADC_low) + 0x8000;
    break;

    case 3: //3rd effect: distortion
    if(output>distortion) output=distortion;
    if(output<-distortion) output=-distortion;
    break;

    case 4: //4th effect: fuzz
    if(output>fuzz) output=32768;
    if(output<-fuzz) output=-32768;
    break;

    case 5: //5th effect: bit crusher
    output = output<<bitCrush;
    break;

    case 6: //6th effect: octaver
    audioBuffer[audioCounter] = ADC_high>>1;
    audioCounter++;
    if(audioCounter >= octaverDelay) audioCounter = 0;
    switch(octaverMode){
      case true: output = ((audioBuffer[(audioCounter*2+octaverDelay/2)%octaverDelay] << 8) | ADC_low) + 0x8000; break;
      case false: output = ((audioBuffer[(int(audioCounter/2)+octaverDelay/2)%octaverDelay] << 8) | ADC_low) + 0x8000; break;}
    break;

    case 7: //7th effect: octave crusher
    audioCounter++;
    if(audioCounter >= MAX_DELAY) audioCounter = 0;
    if(audioCounter%octaveCrusher) writePWM = false;
    break;

    case 8: //8th effect: vibrato
    audioBuffer[audioCounter] = ADC_high>>1;
    audioCounter++;
    if(audioCounter>=lfoDepth){
      audioCounter=0;
      if(countUp){
        for(int p=0;p<10;p++) audioBuffer[lfoDepth+p]=audioBuffer[lfoDepth-1]; 
        lfoDepth++;
        if(lfoDepth>=vibratoDepth) countUp=false;
      }
      else {
        lfoDepth--;
        if(lfoDepth<=MIN_VIBRATO) countUp=true;
      }
    }
    output = ((audioBuffer[audioCounter] << 8) | ADC_low) + 0x8000;
    break;

    case 9: //9th effect: chorus
    audioBuffer[audioCounter] = ADC_high>>1;
    audioCounter++;
    if(audioCounter>=lfoDepth){
      audioCounter=0;
      if(countUp){
        for(int p=0;p<10;p++) audioBuffer[lfoDepth+p]=audioBuffer[lfoDepth-1]; 
        lfoDepth++;
        if(lfoDepth>=chorusDepth) countUp=false;
      }
      else {
        lfoDepth--;
        if(lfoDepth<=MIN_CHORUS) countUp=true;
      }
    }
    output = (((audioBuffer[audioCounter] << 8) | ADC_low) + 0x8000) + output;
    break;
  }

  //write the PWM signal
  if (writePWM){
    OCR4AL = ((output + 0x8000) >> 8);
    OCR4BL = output;
  }

  // Reset flag
  writePWM = true; 
  
}

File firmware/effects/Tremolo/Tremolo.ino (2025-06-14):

/*
  Tremolo.ino modulates the volume with a sinewave.

  Part of the pedalSHIELD-MEGA project: https://github.com/nablum/pedalSHIELD-MEGA

  Copyright (c) 2025 Nablum
  SPDX-License-Identifier: MIT

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
  THE SOFTWARE IS PROVIDED "AS IS", WITHOUT WARRANTY OF ANY KIND, EXPRESS OR
  IMPLIED, INCLUDING BUT NOT LIMITED TO THE WARRANTIES OF MERCHANTABILITY,
  FITNESS FOR A PARTICULAR PURPOSE AND NONINFRINGEMENT. IN NO EVENT SHALL THE
  AUTHORS OR COPYRIGHT HOLDERS BE LIABLE FOR ANY CLAIM, DAMAGES OR OTHER
  LIABILITY, WHETHER IN AN ACTION OF CONTRACT, TORT OR OTHERWISE, ARISING FROM,
  OUT OF OR IN CONNECTION WITH THE SOFTWARE OR THE USE OR OTHER DEALINGS IN THE
  SOFTWARE.
*/

//display parameters
#include "U8glib.h"
U8GLIB_SH1106_128X64 u8g(U8G_I2C_OPT_NO_ACK);

//defining hardware resources
#define LED 13
#define FOOTSWITCH 12
#define TOGGLE 2
#define PUSHBUTTON_1 A5
#define PUSHBUTTON_2 A4

//defining the output PWM parameters
#define PWM_FREQ 0x00FF // pwm frequency - 31.3KHz
#define PWM_MODE 0 // Fast (1) or Phase Correct (0)
#define PWM_QTY 2 // 2 PWMs in parallel

//system variables
int output,counter=0;
unsigned int ADC_low, ADC_high;

//effect variables
int speedy = 4;
int sample = 0;
int divider = 0;

//waveform for volume modulation
const byte waveform[]=
{
0x0,0x1,0x1,0x2,0x2,0x2,0x3,0x3,0x4,0x4,0x4,0x5,0x5,0x5,0x6,0x6,0x7,0x7,0x7,0x8,
0x8,0x9,0x9,0x9,0xa,0xa,0xb,0xb,0xb,0xc,0xc,0xd,0xd,0xd,0xe,0xe,0xe,0xf,0xf,0x10,
0x10,0x10,0x11,0x11,0x12,0x12,0x12,0x13,0x13,0x14,0x14,0x14,0x15,0x15,0x16,0x16,0x16,0x17,0x17,0x17,
0x18,0x18,0x19,0x19,0x19,0x1a,0x1a,0x1b,0x1b,0x1b,0x1c,0x1c,0x1d,0x1d,0x1d,0x1e,0x1e,0x1e,0x1f,0x1f,
0x20,0x20,0x20,0x21,0x21,0x22,0x22,0x22,0x23,0x23,0x24,0x24,0x24,0x25,0x25,0x26,0x26,0x26,0x27,0x27,
0x27,0x28,0x28,0x29,0x29,0x29,0x2a,0x2a,0x2b,0x2b,0x2b,0x2c,0x2c,0x2d,0x2d,0x2d,0x2e,0x2e,0x2f,0x2f,
0x2f,0x30,0x30,0x30,0x31,0x31,0x32,0x32,0x32,0x33,0x33,0x34,0x34,0x34,0x35,0x35,0x36,0x36,0x36,0x37,
0x37,0x38,0x38,0x38,0x39,0x39,0x39,0x3a,0x3a,0x3b,0x3b,0x3b,0x3c,0x3c,0x3d,0x3d,0x3d,0x3e,0x3e,0x3f,
0x3f,0x3f,0x40,0x40,0x41,0x41,0x41,0x42,0x42,0x42,0x43,0x43,0x44,0x44,0x44,0x45,0x45,0x46,0x46,0x46,
0x47,0x47,0x48,0x48,0x48,0x49,0x49,0x4a,0x4a,0x4a,0x4b,0x4b,0x4b,0x4c,0x4c,0x4d,0x4d,0x4d,0x4e,0x4e,
0x4f,0x4f,0x4f,0x50,0x50,0x51,0x51,0x51,0x52,0x52,0x53,0x53,0x53,0x54,0x54,0x54,0x55,0x55,0x56,0x56,
0x56,0x57,0x57,0x58,0x58,0x58,0x59,0x59,0x5a,0x5a,0x5a,0x5b,0x5b,0x5b,0x5c,0x5c,0x5d,0x5d,0x5d,0x5e,
0x5e,0x5f,0x5f,0x5f,0x60,0x60,0x61,0x61,0x61,0x62,0x62,0x63,0x63,0x63,0x64,0x64,0x64,0x65,0x65,0x66,
0x66,0x66,0x67,0x67,0x68,0x68,0x68,0x69,0x69,0x6a,0x6a,0x6a,0x6b,0x6b,0x6c,0x6c,0x6c,0x6d,0x6d,0x6d,
0x6e,0x6e,0x6f,0x6f,0x6f,0x70,0x70,0x71,0x71,0x71,0x72,0x72,0x73,0x73,0x73,0x74,0x74,0x75,0x75,0x75,
0x76,0x76,0x76,0x77,0x77,0x78,0x78,0x78,0x79,0x79,0x7a,0x7a,0x7a,0x7b,0x7b,0x7c,0x7c,0x7c,0x7d,0x7d,
0x7e,0x7e,0x7e,0x7f,0x7f,0x7f,0x80,0x80,0x81,0x81,0x81,0x82,0x82,0x83,0x83,0x83,0x84,0x84,0x85,0x85,
0x85,0x86,0x86,0x87,0x87,0x87,0x88,0x88,0x88,0x89,0x89,0x8a,0x8a,0x8a,0x8b,0x8b,0x8c,0x8c,0x8c,0x8d,
0x8d,0x8e,0x8e,0x8e,0x8f,0x8f,0x8f,0x90,0x90,0x91,0x91,0x91,0x92,0x92,0x93,0x93,0x93,0x94,0x94,0x95,
0x95,0x95,0x96,0x96,0x97,0x97,0x97,0x98,0x98,0x98,0x99,0x99,0x9a,0x9a,0x9a,0x9b,0x9b,0x9c,0x9c,0x9c,
0x9d,0x9d,0x9e,0x9e,0x9e,0x9f,0x9f,0xa0,0xa0,0xa0,0xa1,0xa1,0xa1,0xa2,0xa2,0xa3,0xa3,0xa3,0xa4,0xa4,
0xa5,0xa5,0xa5,0xa6,0xa6,0xa7,0xa7,0xa7,0xa8,0xa8,0xa9,0xa9,0xa9,0xaa,0xaa,0xaa,0xab,0xab,0xac,0xac,
0xac,0xad,0xad,0xae,0xae,0xae,0xaf,0xaf,0xb0,0xb0,0xb0,0xb1,0xb1,0xb2,0xb2,0xb2,0xb3,0xb3,0xb3,0xb4,
0xb4,0xb5,0xb5,0xb5,0xb6,0xb6,0xb7,0xb7,0xb7,0xb8,0xb8,0xb9,0xb9,0xb9,0xba,0xba,0xbb,0xbb,0xbb,0xbc,
0xbc,0xbc,0xbd,0xbd,0xbe,0xbe,0xbe,0xbf,0xbf,0xc0,0xc0,0xc0,0xc1,0xc1,0xc2,0xc2,0xc2,0xc3,0xc3,0xc4,
0xc4,0xc4,0xc5,0xc5,0xc5,0xc6,0xc6,0xc7,0xc7,0xc7,0xc8,0xc8,0xc8,0xc7,0xc7,0xc7,0xc6,0xc6,0xc5,0xc5,
0xc5,0xc4,0xc4,0xc4,0xc3,0xc3,0xc2,0xc2,0xc2,0xc1,0xc1,0xc0,0xc0,0xc0,0xbf,0xbf,0xbe,0xbe,0xbe,0xbd,
0xbd,0xbc,0xbc,0xbc,0xbb,0xbb,0xbb,0xba,0xba,0xb9,0xb9,0xb9,0xb8,0xb8,0xb7,0xb7,0xb7,0xb6,0xb6,0xb5,
0xb5,0xb5,0xb4,0xb4,0xb3,0xb3,0xb3,0xb2,0xb2,0xb2,0xb1,0xb1,0xb0,0xb0,0xb0,0xaf,0xaf,0xae,0xae,0xae,
0xad,0xad,0xac,0xac,0xac,0xab,0xab,0xaa,0xaa,0xaa,0xa9,0xa9,0xa9,0xa8,0xa8,0xa7,0xa7,0xa7,0xa6,0xa6,
0xa5,0xa5,0xa5,0xa4,0xa4,0xa3,0xa3,0xa3,0xa2,0xa2,0xa1,0xa1,0xa1,0xa0,0xa0,0xa0,0x9f,0x9f,0x9e,0x9e,
0x9e,0x9d,0x9d,0x9c,0x9c,0x9c,0x9b,0x9b,0x9a,0x9a,0x9a,0x99,0x99,0x98,0x98,0x98,0x97,0x97,0x97,0x96,
0x96,0x95,0x95,0x95,0x94,0x94,0x93,0x93,0x93,0x92,0x92,0x91,0x91,0x91,0x90,0x90,0x8f,0x8f,0x8f,0x8e,
0x8e,0x8e,0x8d,0x8d,0x8c,0x8c,0x8c,0x8b,0x8b,0x8a,0x8a,0x8a,0x89,0x89,0x88,0x88,0x88,0x87,0x87,0x87,
0x86,0x86,0x85,0x85,0x85,0x84,0x84,0x83,0x83,0x83,0x82,0x82,0x81,0x81,0x81,0x80,0x80,0x7f,0x7f,0x7f,
0x7e,0x7e,0x7e,0x7d,0x7d,0x7c,0x7c,0x7c,0x7b,0x7b,0x7a,0x7a,0x7a,0x79,0x79,0x78,0x78,0x78,0x77,0x77,
0x76,0x76,0x76,0x75,0x75,0x75,0x74,0x74,0x73,0x73,0x73,0x72,0x72,0x71,0x71,0x71,0x70,0x70,0x6f,0x6f,
0x6f,0x6e,0x6e,0x6d,0x6d,0x6d,0x6c,0x6c,0x6c,0x6b,0x6b,0x6a,0x6a,0x6a,0x69,0x69,0x68,0x68,0x68,0x67,
0x67,0x66,0x66,0x66,0x65,0x65,0x64,0x64,0x64,0x63,0x63,0x63,0x62,0x62,0x61,0x61,0x61,0x60,0x60,0x5f,
0x5f,0x5f,0x5e,0x5e,0x5d,0x5d,0x5d,0x5c,0x5c,0x5b,0x5b,0x5b,0x5a,0x5a,0x5a,0x59,0x59,0x58,0x58,0x58,
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
};
 
void setup()
{
  //setup display
  u8g.firstPage(); 
  do{
    u8g.setFont(u8g_font_helvR18r);
    u8g.drawStr( 5, 30, "TREMOLO");    
    u8g.drawStr( 20, 60, "EFFECT");
  } while( u8g.nextPage() );
 
  //setup IO
  pinMode(FOOTSWITCH, INPUT_PULLUP);
  pinMode(TOGGLE, INPUT_PULLUP);
  pinMode(PUSHBUTTON_1, INPUT_PULLUP);
  pinMode(PUSHBUTTON_2, INPUT_PULLUP);
  pinMode(LED, OUTPUT);
  pinMode(6, OUTPUT); //PWM0 as output
  pinMode(7, OUTPUT); //PWM1 as output
 
  //setup ADC
  ADMUX = 0x60; // left adjust, adc0, internal vcc
  ADCSRA = 0xe5; // turn on adc, ck/32, auto trigger
  ADCSRB = 0x00; // ADC free running mode
  DIDR0 = 0x01; // turn off digital inputs for adc0
 
  //setup PWM
  TCCR4A = (((PWM_QTY - 1) << 5) | 0x80 | (PWM_MODE << 1)); //
  TCCR4B = ((PWM_MODE << 3) | 0x11); // ck/1
  TIMSK4 = 0x20; // interrupt on capture interrupt
  ICR4H = (PWM_FREQ >> 8);
  ICR4L = (PWM_FREQ & 0xff);
  DDRB |= ((PWM_QTY << 1) | 0x02); // turn on outputs
  sei(); // turn on interrupts - not really necessary with arduino
}

void loop() 
{
  if (digitalRead(!FOOTSWITCH)) digitalWrite(LED, HIGH); 
  else  digitalWrite(LED, LOW);
}
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

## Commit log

2024-09-20 kicad project update
    [pedalSHIELD_MEGA.kicad_pcb, pedalSHIELD_MEGA.kicad_sch]
2025-03-25 freecad project update
    [ArduinoMega_2560.STEP, pedalSHIELD_MEGA.FCStd, pedalSHIELD_MEGA_PCB.step]
2025-03-27 move from freecad to openscad
    [ArduinoMega_2560.STEP, ArduinoMega_2560.stl, pedalSHIELD_MEGA.FCStd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]
2025-04-09 rev 2.1
    [pedalSHIELD_MEGA.kicad_pcb, pedalSHIELD_MEGA.step]
2025-04-09 3D model update
    [displayOLED.stl, pinHeader.stl]
2025-04-09 pedal assembly
    [lib.scad, pedalSHIELD_MEGA.scad]
2025-04-10 case base design
    [lib.scad, pedalSHIELD_MEGA.scad]
2025-04-10 case left side design
    [pedalSHIELD_MEGA.scad]
2025-04-10 case bottom/right side design
    [pedalSHIELD_MEGA.scad]
2025-04-12 top panel design
    [lib.scad, pedalSHIELD_MEGA.scad]
2025-04-14 board mounts
    [lib.scad, pedalSHIELD_MEGA.scad]
2025-04-14 export .stl
    [pedalSHIELD_MEGA.scad, pedalSHIELD_MEGA.stl]
2025-04-15 svg export
    [pedalSHIELD_MEGA.scad]
2025-04-18 chorus and vibrato added to multi-effects
    [ChorusOrVibrato.ino, MultiEffects.ino]

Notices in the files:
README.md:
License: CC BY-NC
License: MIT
